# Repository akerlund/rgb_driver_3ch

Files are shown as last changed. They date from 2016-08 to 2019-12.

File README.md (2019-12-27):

# LED driver PCB, 3ch RGB

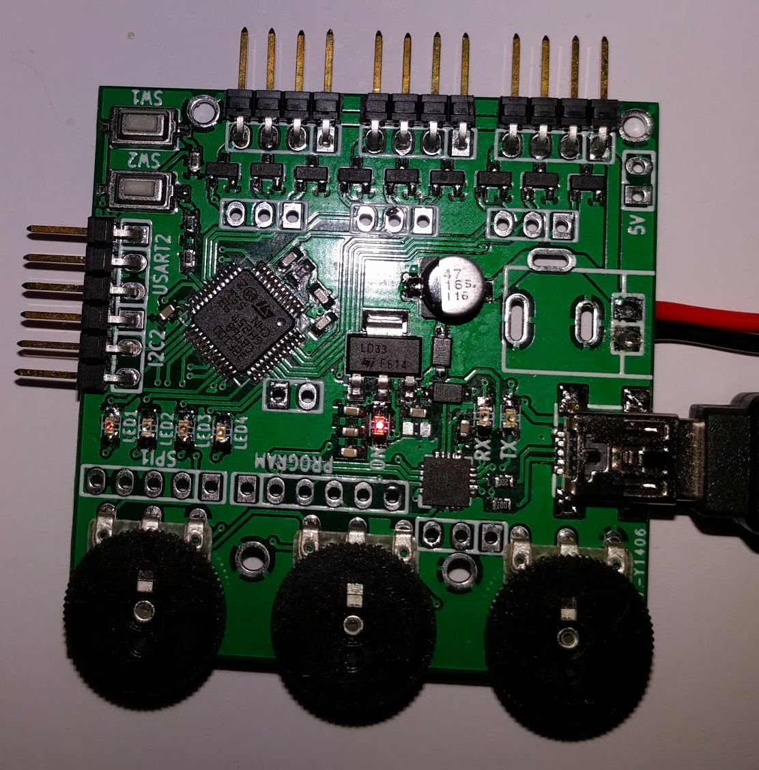
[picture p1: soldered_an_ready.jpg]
Version Three


STM32F100 microcontroller with small SOT23 MOSFETs to drive 12V LED strips.
Four LEDs and two buttons for custom use.
Three potentiometers for controlling the light; HSL, i.e., Hue, Saturation and Light.
A CP2102 serial to USB interface.
Pinout for other peripherals, i.e., I2C, SPI and UART.

## Build

Using the ARM compiler (arm-none-eabi), which can be installed with

```
sudo apt-get install gcc-arm-none-eabi
```
then change directory and run the make file
```
cd code
make
```

## Program
I use Devilholk's verion of [stm32flash](https://github.com/devilholk/stm32flash),
with a cheap CP2102 USB to UART Bridge Controller.

### Programming sequence example

```
~/rgb_driver_3ch$ stm32flash -b 115200 -Rcs.rts -Bcs.dtr -w code/build/driver_rgb_3ch.bin /dev/ttyUSB0
stm32flash - http://stm32flash.googlecode.com/

Using Parser : Raw BINARY
Serial Config: 115200 8E1
Version      : 0x22
Option 1     : 0x00
Option 2     : 0x00
Device ID    : 0x0420 (Medium-density VL)
RAM          : 8KiB  (512b reserved by bootloader)
Flash        : 128KiB (sector size: 4x1024)
Option RAM   : 15b
System RAM   : 2KiB

Wrote address 0x08003304 (100.00%) Done.
```

### Pin configurations
Make sure you connect cables like this;

PCB | CP2102
-- | --
3.3V | N/C
GND | GND
TX | RXI
RX | TXO
RESET | RTS
BOOT | DTR

If you haven't, remember to add your username to the dialout group

```
sudo adduser <user_name> dialout
```

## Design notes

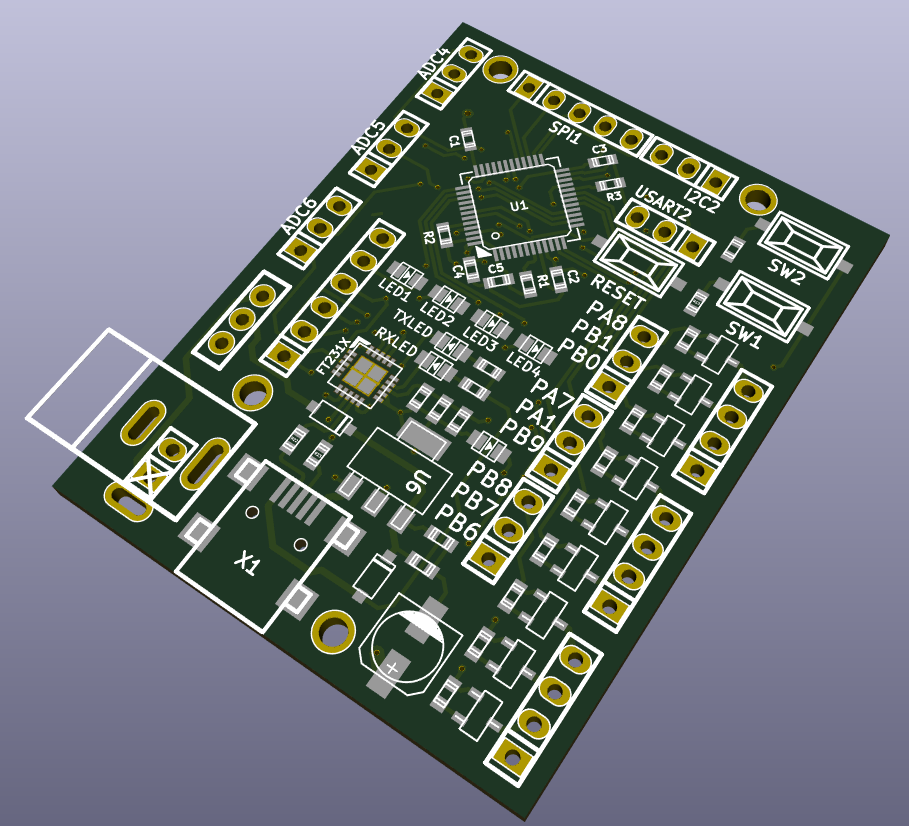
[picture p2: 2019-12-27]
kicad/version_2.png

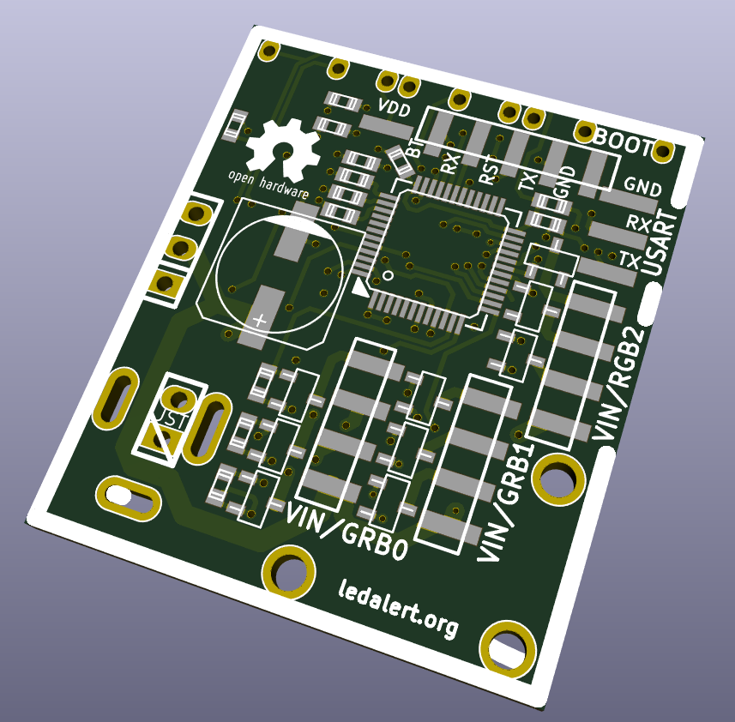
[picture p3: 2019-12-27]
kicad/version_1.png

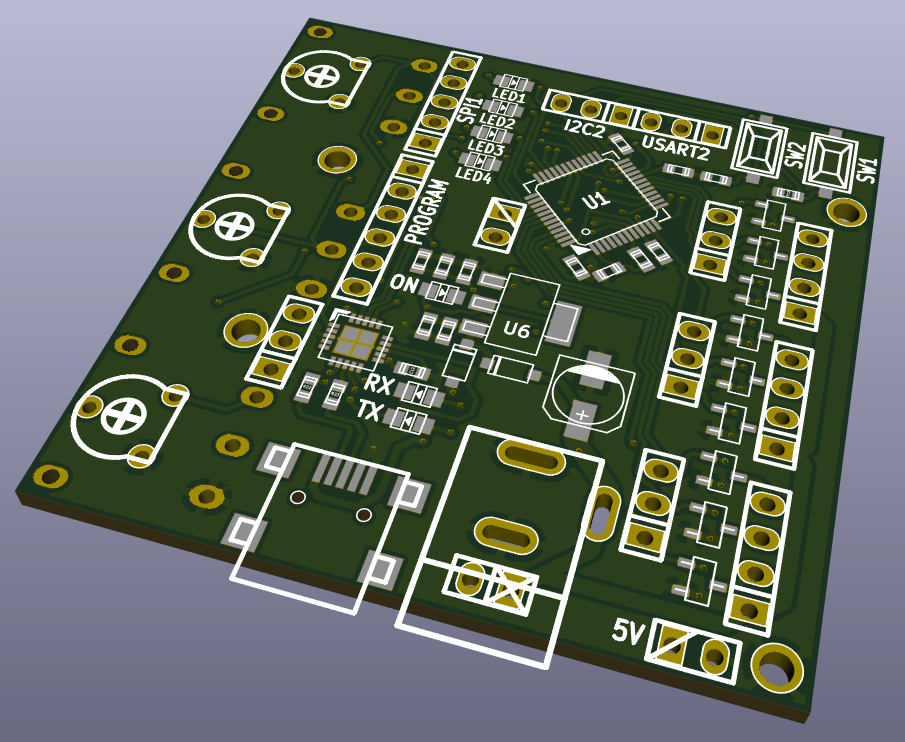
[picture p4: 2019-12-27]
kicad/version_3.png

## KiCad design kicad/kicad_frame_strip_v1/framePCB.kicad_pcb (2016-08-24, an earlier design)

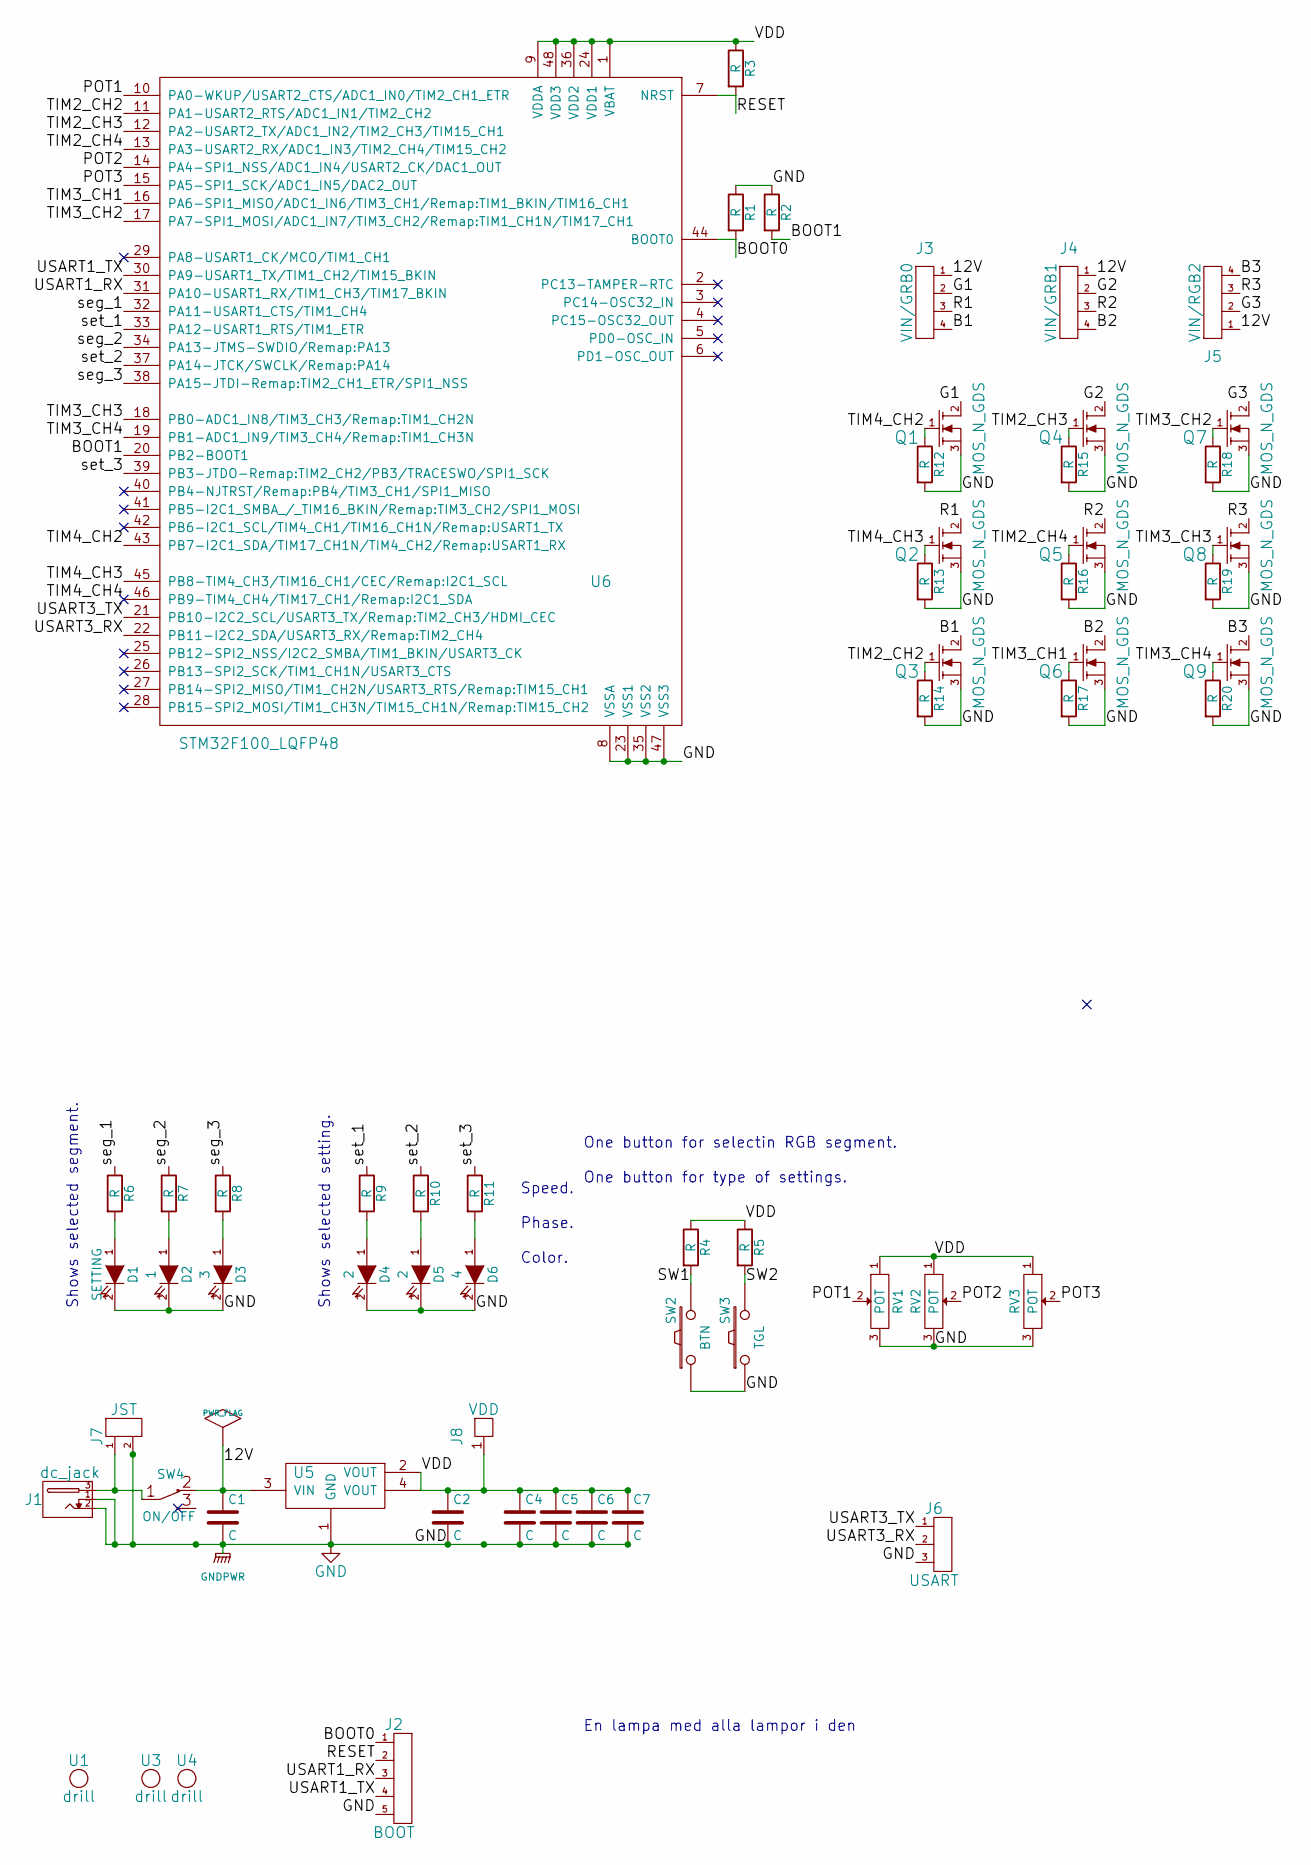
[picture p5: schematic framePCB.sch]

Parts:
C1: C; c_elec_8x6.5
C2, C4, C5, C6, C7: C; c_0603
D1: SETTING; Led_0603
D2: 1; Led_0603
D3: 3; Led_0603
D4, D5: 2; Led_0603
D6: 4; Led_0603
J1: dc_jack; dc_socket
J2: BOOT; smd_pin_5
J3: VIN/GRB0; smd_pin_4
J4: VIN/GRB1; smd_pin_4
J5: VIN/RGB2; smd_pin_4
J6: USART; smd_pin_3
J7: JST; pin_strip_2
J8: VDD; pin_strip_1
Q1, Q2, Q3, Q4, Q5, Q6, Q7, Q8, Q9: MOS_N_GDS; sot23
R1, R2, R3, R4, R5, R6, R7, R8, R9, R10, R11, R12, R13, R14, R15, R16, R17, R18, R19, R20: R; r_0603
RV1, RV2, RV3: POT; pot_eBay
SW2: BTN; smd_switch
SW3: TGL; smd_switch
SW4: ON/OFF; pin_socket_3
U1, U3, U4: drill; drill_2.0mm
U5: V_Reg_SOT; sot223
U6: STM32F100_LQFP48; lqfp48

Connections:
/12V: C1.1, J3.1, J4.1, J5.1, SW4.2 (NC), U5.3 (VIN)
/B1: J3.4, Q3.2 (D)
/B2: J4.4, Q6.2 (D)
/B3: J5.4, Q9.2 (D)
/BOOT0: J2.1, R1.2, U6.44 (BOOT0)
/BOOT1: R2.2, U6.20 (PB2-BOOT1)
/G1: J3.2, Q1.2 (D)
/G2: J4.2, Q4.2 (D)
/G3: J5.2, Q7.2 (D)
/POT1: RV1.2, U6.10 (PA0-WKUP/USART2_CTS/ADC1_IN0/TIM2_CH1_E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)
/POT2: RV2.2, U6.14 (PA4-SPI1_NSS/ADC1_IN4/USART2_CK/DAC1_OUT)
/POT3: RV3.2, U6.15 (PA5-SPI1_SCK/ADC1_IN5/DAC2_OUT)
/R1: J3.3, Q2.2 (D)
/R2: J4.3, Q5.2 (D)
/R3: J5.3, Q8.2 (D)
/RESET: J2.2, R3.2, U6.7 (NRST)
/SW1: R4.2, SW2.2
/SW2: R5.2, SW3.2
/TIM2_CH2: Q3.1 (G), R14.1, U6.11 (PA1-USART2_RTS/ADC1_IN1/TIM2_CH2)
/TIM2_CH3: Q4.1 (G), R15.1, U6.12 (PA2-USART2_TX/ADC1_IN2/TIM2_CH3/TIM15_C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)
/TIM2_CH4: Q5.1 (G), R16.1, U6.13 (PA3-USART2_RX/ADC1_IN3/TIM2_CH4/TIM15_C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)
/TIM3_CH1: Q6.1 (G), R17.1, U6.16 (PA6-SPI1_MISO/ADC1_IN6/TIM3_CH1/Remap:T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)
/TIM3_CH2: Q7.1 (G), R18.1, U6.17 (PA7-SPI1_MOSI/ADC1_IN7/TIM3_CH2/Remap:T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)
/TIM3_CH3: Q8.1 (G), R19.1, U6.18 (PB0-ADC1_IN8/TIM3_CH3/Remap:TIM1_CH2N)
/TIM3_CH4: Q9.1 (G), R20.1, U6.19 (PB1-ADC1_IN9/TIM3_CH4/Remap:TIM1_CH3N)
/TIM4_CH2: Q1.1 (G), R12.1, U6.43 (PB7-I2C1_SDA/TIM17_CH1N/TIM4_CH2/Remap: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)
/TIM4_CH3: Q2.1 (G), R13.1, U6.45 (PB8-TIM4_CH3/TIM16_CH1/CEC/Remap:I2C1_S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)
/USART1_RX: J2.3, U6.31 (PA10-USART1_RX/TIM1_CH3/TIM17_BKIN)
/USART1_TX: J2.4, U6.30 (PA9-USART1_TX/TIM1_CH2/TIM15_BKIN)
/USART3_RX: J6.2, U6.22 (PB11-I2C2_SDA/USART3_RX/Remap:TIM2_CH4)
/USART3_TX: J6.1, U6.21 (PB10-I2C2_SCL/USART3_TX/Remap:TIM2_CH3/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)
/VDD: C2.1, C4.1, C5.1, C6.1, C7.1, J8.1, R3.1, R4.1, R5.1, RV1.1, RV2.1, RV3.1, U5.2 (VOUT), U5.4 (VOUT), U6.1 (VBAT), U6.9 (VDDA), U6.24 (VDD1), U6.36 (VDD2), U6.48 (VDD3)
/seg_1: R6.1, U6.32 (PA11-USART1_CTS/TIM1_CH4)
/seg_2: R7.1, U6.34 (PA13-JTMS-SWDIO/Remap:PA13)
/seg_3: R8.1, U6.38 (PA15-JTDI-Remap:TIM2_CH1_ETR/SPI1_NSS)
/set_1: R9.1, U6.33 (PA12-USART1_RTS/TIM1_ETR)
/set_2: R10.1, U6.37 (PA14-JTCK/SWCLK/Remap:PA14)
/set_3: R11.1, U6.39 (PB3-JTDO-Remap:TIM2_CH2/PB3/TRACESWO/SP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)
GNDPWR: C1.2, C2.2, C4.2, C5.2, C6.2, C7.2, D1.2 (K), D2.2 (K), D3.2 (K), D4.2 (K), D5.2 (K), D6.2 (K), J1.1, J1.2, J2.5, J6.3, J7.2, Q1.3 (S), Q2.3 (S), Q3.3 (S), Q4.3 (S), Q5.3 (S), Q6.3 (S), Q7.3 (S), Q8.3 (S), Q9.3 (S), R1.1, R2.1, R12.2, R13.2, R14.2, R15.2, R16.2, R17.2, R18.2, R19.2, R20.2, RV1.3, RV2.3, RV3.3, SW2.1, SW3.1, U5.1 (GND), U6.8 (VSSA), U6.23 (VSS1), U6.35 (VSS2), U6.47 (VSS3)
unnamed: D1.1 (A), R6.2
unnamed: D2.1 (A), R7.2
unnamed: D3.1 (A), R8.2
unnamed: D4.1 (A), R9.2
unnamed: D5.1 (A), R10.2
unnamed: D6.1 (A), R11.2
unnamed: J1.3, J7.1, SW4.1 (COM)

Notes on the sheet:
One button for selectin RGB segment. One button for type of settings.
Shows selected segment.
Shows selected setting.
Speed. Phase. Color.
En lampa med alla lampor i den

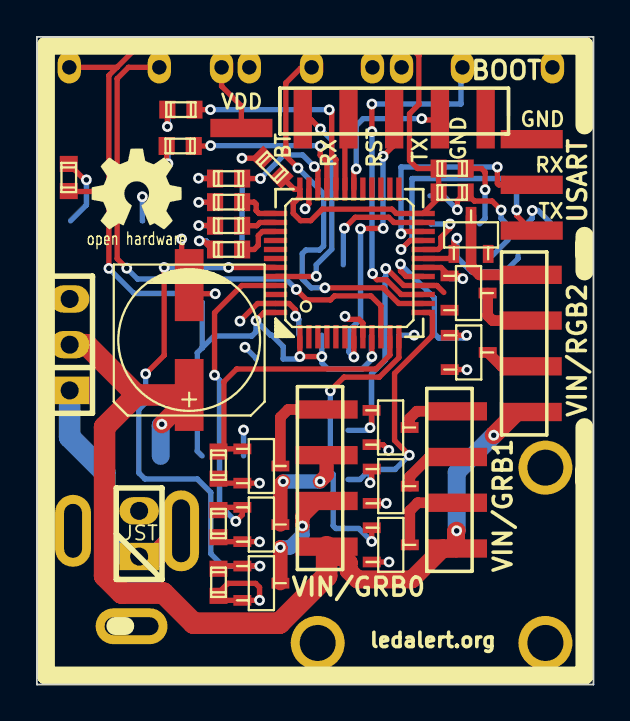
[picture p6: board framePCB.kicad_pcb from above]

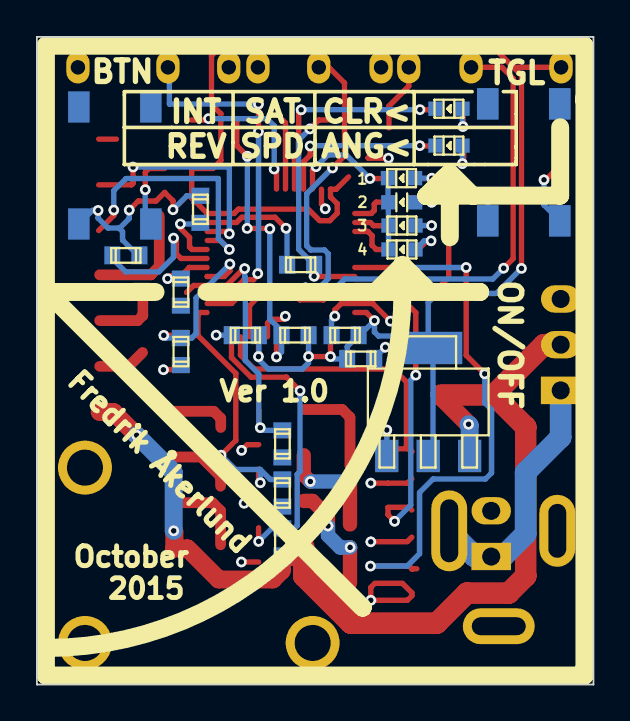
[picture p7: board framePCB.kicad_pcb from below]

Board: 2 copper layers, 30.9 x 36.0 mm, 60 parts (21 on the bottom side), 46 nets.

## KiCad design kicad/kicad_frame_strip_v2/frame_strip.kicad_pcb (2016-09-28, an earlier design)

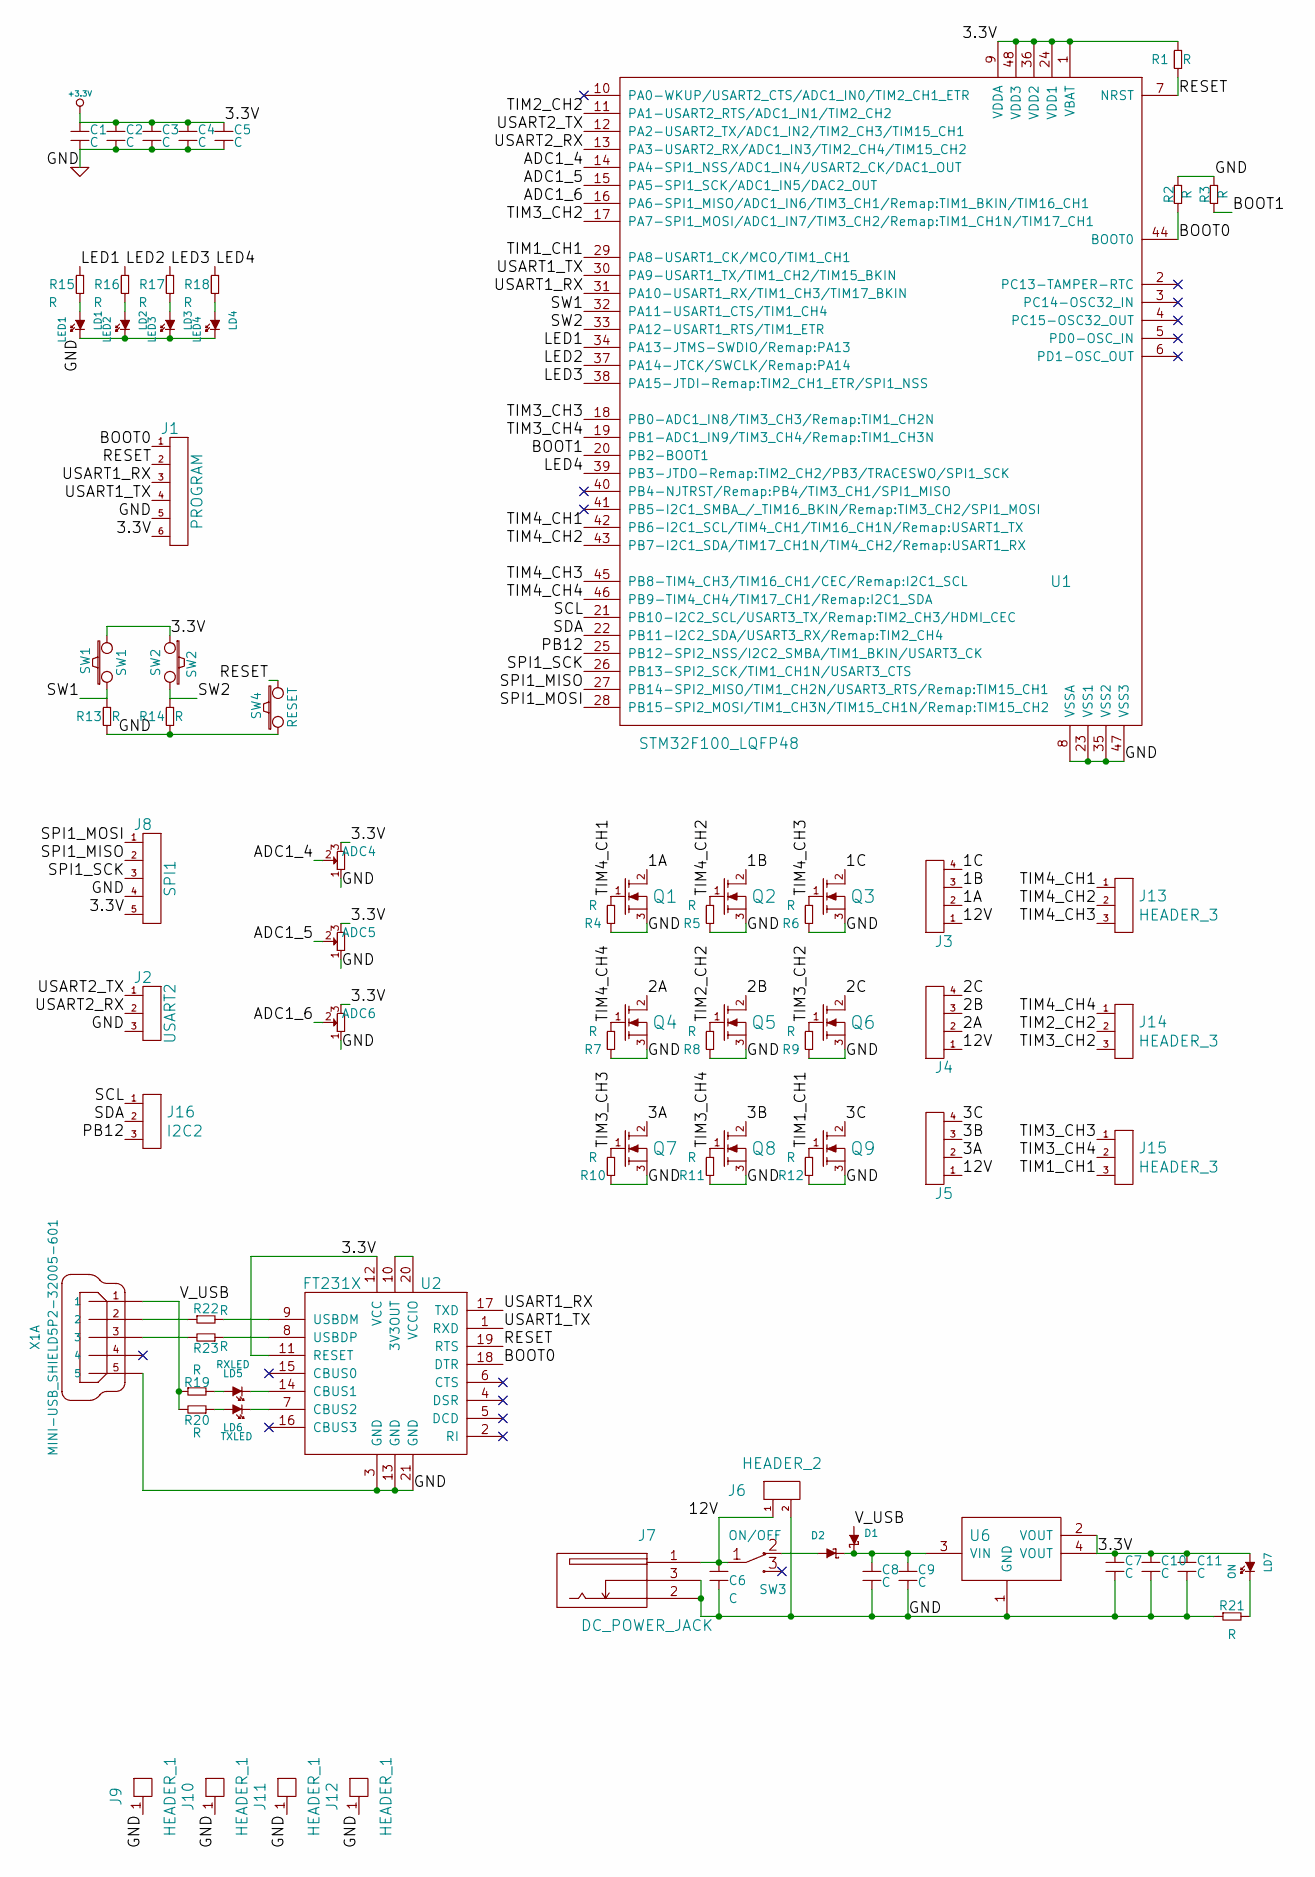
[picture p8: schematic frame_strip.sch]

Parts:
ADC4, ADC5, ADC6: POT; pin_socket_3
C1, C2, C3, C4, C5, C7, C8, C9, C10, C11: C; c_0603
C6: C; c_elec_5x5.3
D1, D2: SCHOTTKY; sod123
J1: PROGRAM; pin_strip_6
J2: USART2; pin_strip_3
J3, J4, J5: HEADER_4; pin_strip_4
J6: HEADER_2; pin_socket_2
J7: DC_POWER_JACK; dc_socket
J8: SPI1; pin_strip_5
J9, J10, J11, J12: HEADER_1; drill_2.0mm
J13, J14, J15: HEADER_3; pin_socket_3
J16: I2C2; pin_socket_3
LD1: LED1; Led_0805
LD2: LED2; Led_0805
LD3: LED3; Led_0805
LD4: LED4; Led_0805
LD5: RXLED; Led_0805
LD6: TXLED; Led_0805
LD7: ON; Led_0805
Q1, Q2, Q3, Q4, Q5, Q6, Q7, Q8, Q9: MOS_N_GDS; sot23
R1, R2, R3, R4, R5, R6, R7, R8, R9, R10, R11, R12, R13, R14, R15, R16, R17, R18, R19, R20, R21, R22, R23: R; r_0603
SW1: SW1; smd_push
SW2: SW2; smd_push
SW3: ON/OFF; switch_mmp122-r
SW4: RESET; smd_push
U1: STM32F100_LQFP48; lqfp48
U2: FT231X; qfn-20
U6: sot223
X1: MINI-USB_SHIELD5P2-32005-601; conn_usb_B_mini_smd

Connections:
+3.3V: ADC4.3, ADC5.3, ADC6.3, C1.1, C2.1, C3.1, C4.1, C5.1, C7.1, C10.1, C11.1, J1.6, J8.5, LD7.1 (A), R1.1, SW1.2, SW2.1, U1.1 (VBAT), U1.9 (VDDA), U1.24 (VDD1), U1.36 (VDD2), U1.48 (VDD3), U2.11 (RESET), U2.12 (VCC), U6.2 (VOUT), U6.4 (VOUT)
/1A: J3.2, Q1.2 (D)
/1B: J3.3, Q2.2 (D)
/1C: J3.4, Q3.2 (D)
/2A: J4.2, Q4.2 (D)
/2B: J4.3, Q5.2 (D)
/2C: J4.4, Q6.2 (D)
/3A: J5.2, Q7.2 (D)
/3B: J5.3, Q8.2 (D)
/3C: J5.4, Q9.2 (D)
/12V: C6.1, J3.1, J4.1, J5.1, J6.1, J7.1, SW3.1 (COM)
/ADC1_4: ADC4.2, U1.14 (PA4-SPI1_NSS/ADC1_IN4/USART2_CK/DAC1_OUT)
/ADC1_5: ADC5.2, U1.15 (PA5-SPI1_SCK/ADC1_IN5/DAC2_OUT)
/ADC1_6: ADC6.2, U1.16 (PA6-SPI1_MISO/ADC1_IN6/TIM3_CH1/Remap:T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)
/BOOT0: J1.1, R2.2, U1.44 (BOOT0), U2.18 (DTR)
/BOOT1: R3.2, U1.20 (PB2-BOOT1)
/LED1: R15.1, U1.34 (PA13-JTMS-SWDIO/Remap:PA13)
/LED2: R16.1, U1.37 (PA14-JTCK/SWCLK/Remap:PA14)
/LED3: R17.1, U1.38 (PA15-JTDI-Remap:TIM2_CH1_ETR/SPI1_NSS)
/LED4: R18.1, U1.39 (PB3-JTDO-Remap:TIM2_CH2/PB3/TRACESWO/SP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)
/PB12: J16.3, U1.25 (PB12-SPI2_NSS/I2C2_SMBA/TIM1_BKIN/USART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)
/RESET: J1.2, R1.2, SW4.2, U1.7 (NRST), U2.19 (RTS)
/SCL: J16.1, U1.21 (PB10-I2C2_SCL/USART3_TX/Remap:TIM2_CH3/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)
/SDA: J16.2, U1.22 (PB11-I2C2_SDA/USART3_RX/Remap:TIM2_CH4)
/SPI1_MISO: J8.2, U1.27 (PB14-SPI2_MISO/TIM1_CH2N/USART3_RTS/Rem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)
/SPI1_MOSI: J8.1, U1.28 (PB15-SPI2_MOSI/TIM1_CH3N/TIM15_CH1N/Rem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)
/SPI1_SCK: J8.3, U1.26 (PB13-SPI2_SCK/TIM1_CH1N/USART3_CTS)
/SW1: R13.1, SW1.1, U1.32 (PA11-USART1_CTS/TIM1_CH4)
/SW2: R14.1, SW2.2, U1.33 (PA12-USART1_RTS/TIM1_ETR)
/TIM1_CH1: J15.3, Q9.1 (G), R12.1, U1.29 (PA8-USART1_CK/MCO/TIM1_CH1)
/TIM2_CH2: J14.2, Q5.1 (G), R8.1, U1.11 (PA1-USART2_RTS/ADC1_IN1/TIM2_CH2)
/TIM3_CH2: J14.3, Q6.1 (G), R9.1, U1.17 (PA7-SPI1_MOSI/ADC1_IN7/TIM3_CH2/Remap:T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)
/TIM3_CH3: J15.1, Q7.1 (G), R10.1, U1.18 (PB0-ADC1_IN8/TIM3_CH3/Remap:TIM1_CH2N)
/TIM3_CH4: J15.2, Q8.1 (G), R11.1, U1.19 (PB1-ADC1_IN9/TIM3_CH4/Remap:TIM1_CH3N)
/TIM4_CH1: J13.1, Q1.1 (G), R4.1, U1.42 (PB6-I2C1_SCL/TIM4_CH1/TIM16_CH1N/Remap: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)
/TIM4_CH2: J13.2, Q2.1 (G), R5.1, U1.43 (PB7-I2C1_SDA/TIM17_CH1N/TIM4_CH2/Remap: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)
/TIM4_CH3: J13.3, Q3.1 (G), R6.1, U1.45 (PB8-TIM4_CH3/TIM16_CH1/CEC/Remap:I2C1_S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)
/TIM4_CH4: J14.1, Q4.1 (G), R7.1, U1.46 (PB9-TIM4_CH4/TIM17_CH1/Remap:I2C1_SDA)
/USART1_RX: J1.3, U1.31 (PA10-USART1_RX/TIM1_CH3/TIM17_BKIN), U2.17 (TXD)
/USART1_TX: J1.4, U1.30 (PA9-USART1_TX/TIM1_CH2/TIM15_BKIN), U2.1 (RXD)
/USART2_RX: J2.2, U1.13 (PA3-USART2_RX/ADC1_IN3/TIM2_CH4/TIM15_C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)
/USART2_TX: J2.1, U1.12 (PA2-USART2_TX/ADC1_IN2/TIM2_CH3/TIM15_C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)
/V_USB: D1.1 (A), R19.1, R20.2, X1.1
GND: ADC4.1, ADC5.1, ADC6.1, C1.2, C2.2, C3.2, C4.2, C5.2, C6.2, C7.2, C8.2, C9.2, C10.2, C11.2, J1.5, J2.3, J6.2, J7.2, J7.3, J8.4, J9.1, J10.1, J11.1, J12.1, LD1.2 (K), LD2.2 (K), LD3.2 (K), LD4.2 (K), Q1.3 (S), Q2.3 (S), Q3.3 (S), Q4.3 (S), Q5.3 (S), Q6.3 (S), Q7.3 (S), Q8.3 (S), Q9.3 (S), R2.1, R3.1, R4.2, R5.2, R6.2, R7.2, R8.2, R9.2, R10.2, R11.2, R12.2, R13.2, R14.2, R21.1, SW4.1, U1.8 (VSSA), U1.23 (VSS1), U1.35 (VSS2), U1.47 (VSS3), U2.3 (GND), U2.13 (GND), U2.21 (GND), U6.1 (GND), X1.5
unnamed: C8.1, C9.1, D1.2 (K), D2.2 (K), U6.3 (VIN)
unnamed: D2.1 (A), SW3.2 (NC)
unnamed: LD1.1 (A), R15.2
unnamed: LD2.1 (A), R16.2
unnamed: LD3.1 (A), R17.2
unnamed: LD4.1 (A), R18.2
unnamed: LD5.1 (A), R19.2
unnamed: LD5.2 (K), U2.14 (CBUS1)
unnamed: LD6.1 (A), R20.1
unnamed: LD6.2 (K), U2.7 (CBUS2)
unnamed: LD7.2 (K), R21.2
unnamed: R22.1, X1.2
unnamed: R22.2, U2.9 (USBDM)
unnamed: R23.1, U2.8 (USBDP)
unnamed: R23.2, X1.3
unnamed: U2.10 (3V3OUT), U2.20 (VCCIO)

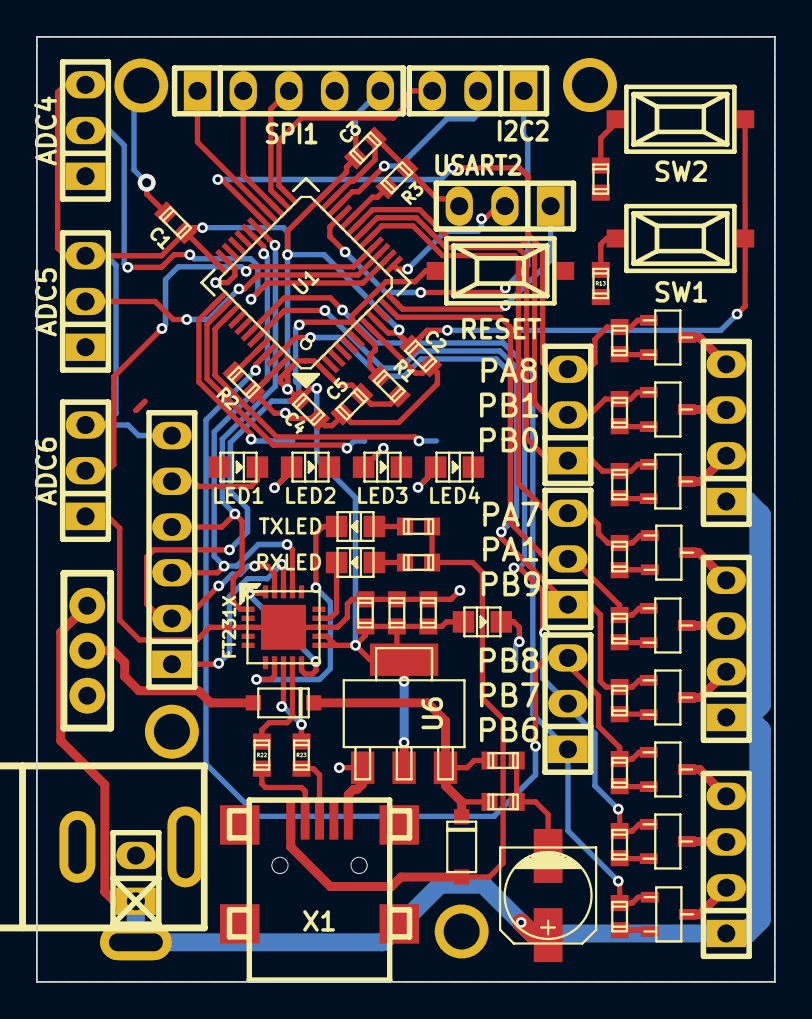
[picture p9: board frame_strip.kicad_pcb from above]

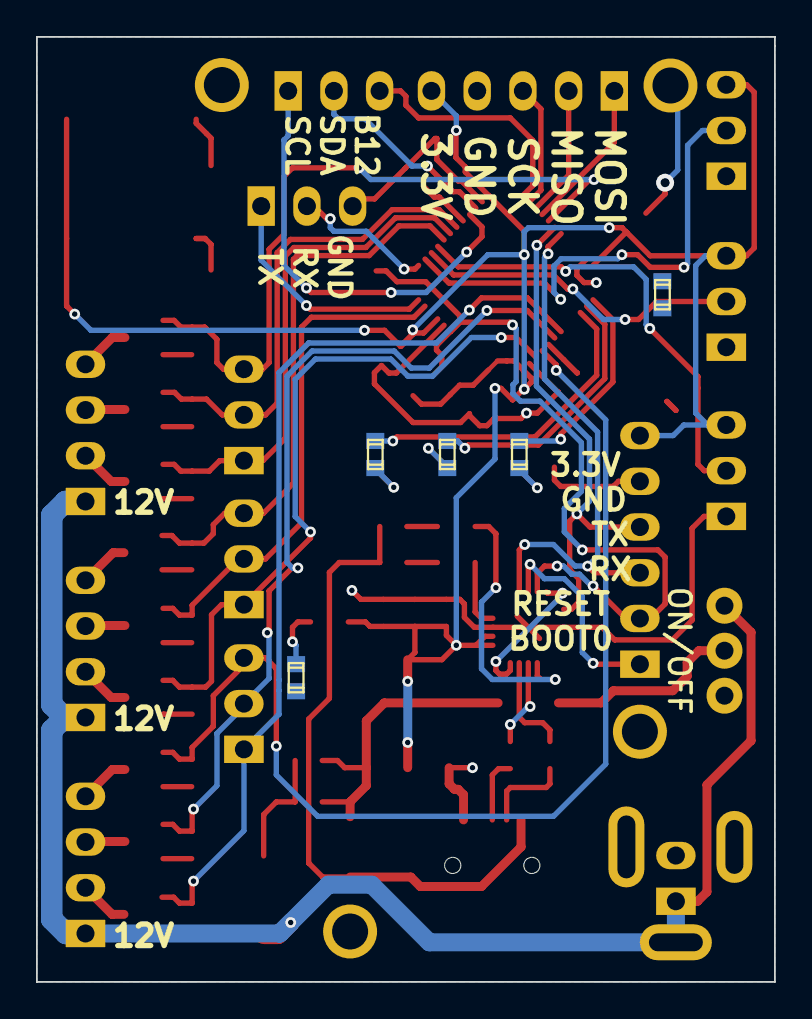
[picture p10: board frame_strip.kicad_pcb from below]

Board: 2 copper layers, 41.0 x 52.5 mm, 79 parts (5 on the bottom side), 60 nets.

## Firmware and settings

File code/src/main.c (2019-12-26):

#include <libopencm3/stm32/rcc.h>
#include <libopencm3/stm32/gpio.h>
#include <libopencm3/stm32/timer.h>
#include <libopencm3/stm32/dma.h>
#include <libopencm3/stm32/adc.h>
#include <libopencm3/stm32/usart.h>
#include <libopencm3/cm3/systick.h>
#include <libopencm3/cm3/nvic.h>

#include "gamma.h"
#include <stdio.h>

/*#define RMAX 4096
#define GMAX 4096
#define BMAX 4096*/

#define RMAX 4096
#define GMAX 3500
#define BMAX 2500

#define led_1 GPIO13
#define led_2 GPIO14
#define led_3 GPIO15
#define led_4 GPIO3

#define adc_pot1 GPIO4
#define adc_pot2 GPIO5
#define adc_pot3 GPIO6

#define btn_1 GPIO11
#define btn_2 GPIO12

// WS2812
#define NUMBER_LEDS 16
#define BIT_0 10
#define BIT_1 29
#define FREQ 400000

const uint16_t    gamma_lut[4096] = {GAMMA_LUT};
volatile uint16_t adc_samples[16];
volatile int      ms_time_delay;
volatile uint8_t  usart_rx_buffer[64];
volatile bool     usart_recieved = false;
volatile uint32_t idle_state_LED_blinker_cnt = 0;

// A struct for keeping track of an average ADC value.
struct value_handler {
  uint32_t  size;
  uint16_t* list;
  uint16_t  index;
};

// A struct for saving data of LED strips.
struct led_strip {
  int H;
  int S;
  int L;
};

// For deciding which LEDs to light up, and to what strip
// the inputs are directed to.
enum states {
  IDLE,
  AUTO,
  STRIP_1,
  STRIP_2,
  STRIP_3
};

// States for a button, for dealing with debouncing.
enum button_states {
  NOT_PUSHED,
  BOUNCE_KEEP,
  PUSHED,
  SUSTAINED
};

// WS2812
struct color {
  uint8_t r;
  uint8_t g;
  uint8_t b;
};

volatile uint8_t led_output_buf[NUMBER_LEDS*24+1];  //42 x 24
volatile struct  color led_input_buf[NUMBER_LEDS];


void sys_tick_handler(void){
  if (ms_time_delay) {
    ms_time_delay--;
  }
}


void sleep_ms(int t){
  ms_time_delay = t;
  while (ms_time_delay);
}


void setup_clock( ){

  rcc_clock_setup_in_hsi_out_24mhz( );

  rcc_periph_clock_enable(RCC_GPIOA);
  rcc_periph_clock_enable(RCC_GPIOB);
  rcc_periph_clock_enable(RCC_AFIO);

  //rcc_periph_clock_enable(RCC_USART2);
  rcc_periph_clock_enable(RCC_ADC1);

  rcc_periph_clock_enable(RCC_TIM1);
  rcc_periph_clock_enable(RCC_TIM2);
  rcc_periph_clock_enable(RCC_TIM3);
  rcc_periph_clock_enable(RCC_TIM4);

  rcc_periph_clock_enable(RCC_DMA1);
}


void setup_timers( ){

  void setup_timer1( ){

    // Clock division ratio and center aligned mode selection.
    TIM1_CR1 = TIM_CR1_CKD_CK_INT | TIM_CR1_CMS_EDGE;

    // Auto reload register.
    TIM1_ARR = 4096-1;

    // Prescaler.
    TIM1_PSC = 0;

    // Event generation register 0 update generation.
    TIM1_EGR = TIM_EGR_UG;

    TIM1_BDTR |= TIM_BDTR_MOE;

    // Output compare 3 mode and preload.
    // Capture/compare mode register, output compare 1 mode,
    // preload enable.
    TIM1_CCMR1 |= TIM_CCMR1_OC2M_PWM1 | TIM_CCMR1_OC2PE;
    TIM1_CCMR1 |= TIM_CCMR1_OC1M_PWM1 | TIM_CCMR1_OC1PE;
    TIM1_CCMR2 |= TIM_CCMR2_OC3M_PWM1 | TIM_CCMR2_OC3PE;
    TIM1_CCMR2 |= TIM_CCMR2_OC4M_PWM1 | TIM_CCMR2_OC4PE;

    // Polarity and state.
    TIM1_CCER |= TIM_CCER_CC1E;

    // ARR reload enable.
    TIM1_CR1 |= TIM_CR1_ARPE;

    // Counter enable.
    TIM1_CR1 |= TIM_CR1_CEN;
  }


  void setup_timer2( ){

    // Clock division ratio and center aligned mode selection.
    TIM2_CR1 = TIM_CR1_CKD_CK_INT | TIM_CR1_CMS_EDGE;

    // Auto reload register.
    TIM2_ARR = 4096-1;

    // Prescaler.
    TIM2_PSC = 0;

    // event generation register 0 update generation.
    TIM2_EGR = TIM_EGR_UG;

    // Output compare 3 mode and preload.
    // Capture/compare mode register, output compare 1 mode,
    // preload enable.
    TIM2_CCMR1 |= TIM_CCMR1_OC1M_PWM1 | TIM_CCMR1_OC1PE | TIM_CCMR1_OC2M_PWM1 | TIM_CCMR1_OC2PE;
    TIM2_CCMR2 |= TIM_CCMR2_OC3M_PWM1 | TIM_CCMR2_OC3PE | TIM_CCMR2_OC4M_PWM1 | TIM_CCMR2_OC4PE;

    // Polarity and state.
    TIM2_CCER |= TIM_CCER_CC2E | TIM_CCER_CC3E | TIM_CCER_CC4E;

    // ARR reload enable.
    TIM2_CR1 |= TIM_CR1_ARPE;

    // Counter enable.
    TIM2_CR1 |= TIM_CR1_CEN;
  }

  void setup_timer3( ){

    // Clock division ratio and center aligned mode selection.
    TIM3_CR1 = TIM_CR1_CKD_CK_INT | TIM_CR1_CMS_EDGE;

    // Period
    TIM3_ARR = 4096-1;

    // Prescaler
    TIM3_PSC = 0;
    TIM3_EGR = TIM_EGR_UG;

    // Output compare 3 mode and preload.
    TIM3_CCMR1 |= TIM_CCMR1_OC1M_PWM1 | TIM_CCMR1_OC1PE | TIM_CCMR1_OC2M_PWM1 | TIM_CCMR1_OC2PE;
    TIM3_CCMR2 |= TIM_CCMR2_OC3M_PWM1 | TIM_CCMR2_OC3PE | TIM_CCMR2_OC4M_PWM1 | TIM_CCMR2_OC4PE;

    // Polarity and state.
    TIM3_CCER |= TIM_CCER_CC1E | TIM_CCER_CC2E | TIM_CCER_CC3E | TIM_CCER_CC4E;

    // ARR reload enable.
    TIM3_CR1 |= TIM_CR1_ARPE;

    // Counter enable.
    TIM3_CR1 |= TIM_CR1_CEN;
  }

  void setup_timer4( ){

    // Clock division ratio and center aligned mode selection.
    TIM4_CR1 = TIM_CR1_CKD_CK_INT | TIM_CR1_CMS_EDGE;

    // Period.
    TIM4_ARR = 4096-1;

    // Prescaler.
    TIM4_PSC = 0;
    TIM4_EGR = TIM_EGR_UG;

    // Output compare 3 mode and preload.
    TIM4_CCMR2 |= TIM_CCMR2_OC3M_PWM1 | TIM_CCMR2_OC3PE | TIM_CCMR2_OC4M_PWM1 | TIM_CCMR2_OC4PE;
    TIM4_CCMR1 |= TIM_CCMR1_OC1M_PWM1 | TIM_CCMR1_OC1PE | TIM_CCMR1_OC2M_PWM1 | TIM_CCMR1_OC2PE;

    // Polarity and state.
    TIM4_CCER |= TIM_CCER_CC1E | TIM_CCER_CC2E | TIM_CCER_CC3E | TIM_CCER_CC4E;

    // ARR reload enable.
    TIM4_CR1 |= TIM_CR1_ARPE;

    // Counter enable.
    TIM4_CR1 |= TIM_CR1_CEN;
  }

  /*
    tim1_ch1 A8
    tim3_ch4 B1
    tim3_ch3 B0

    tim3_ch2 A7
    tim2_ch2 A1
    tim4_ch4 B9

    tim4_ch3 B8
    tim4_ch2 B7
    tim4_ch1 B6
  */

  gpio_set_mode(GPIOA, GPIO_MODE_OUTPUT_10_MHZ, GPIO_CNF_OUTPUT_ALTFN_PUSHPULL,
                GPIO1 | GPIO7 | GPIO8);
  gpio_set_mode(GPIOB, GPIO_MODE_OUTPUT_10_MHZ, GPIO_CNF_OUTPUT_ALTFN_PUSHPULL,
                GPIO0 | GPIO1 | GPIO6 | GPIO7 | GPIO8 | GPIO9);

  setup_timer1( );
  setup_timer2( );
  setup_timer3( );
  setup_timer4( );
}


void setup_timer_for_ws2812( ){

  // LED data out
  gpio_set(GPIOB, GPIO0);
  gpio_set_mode(GPIOB, GPIO_MODE_OUTPUT_50_MHZ, GPIO_CNF_OUTPUT_ALTFN_PUSHPULL, GPIO0);

  TIM3_CR1 = TIM_CR1_CKD_CK_INT | TIM_CR1_CMS_EDGE;

  // Period
  TIM3_ARR = (24000000 / FREQ)-1;

  // Prescaler
  TIM3_PSC = 0;
  TIM3_EGR = TIM_EGR_UG;

  // Output compare 3 mode and preload
  TIM3_CCMR2 |= TIM_CCMR2_OC3M_PWM2 | TIM_CCMR2_OC3PE;

  // Polarity and state
  TIM3_CCER |= TIM_CCER_CC3E;

  // ARR reload enable
  TIM3_CR1 |= TIM_CR1_ARPE;

  // Counter enable
  TIM3_CR1 |= TIM_CR1_CEN;

  TIM3_CCR3 = 0;
}


void set_pwm_strip_1(int R, int G, int B) {

  int cR = gamma_lut[ (R*RMAX) >> 12 ];
  int cG = gamma_lut[ (G*GMAX) >> 12 ];
  int cB = gamma_lut[ (B*BMAX) >> 12 ];

  TIM1_CCR1 = cR;
  TIM3_CCR4 = cG;
  TIM3_CCR3 = cB;
}


void set_pwm_strip_2(int R, int G, int B) {

  int cR = gamma_lut[ (R*RMAX) >> 12 ];
  int cG = gamma_lut[ (G*GMAX) >> 12 ];
  int cB = gamma_lut[ (B*BMAX) >> 12 ];

  TIM3_CCR2 = cR;
  TIM2_CCR2 = cG;
  TIM4_CCR4 = cB;
}


void set_pwm_strip_3(int R, int G, int B) {

  int cR = gamma_lut[ (R*RMAX) >> 12 ];
  int cG = gamma_lut[ (G*GMAX) >> 12 ];
  int cB = gamma_lut[ (B*BMAX) >> 12 ];

  TIM4_CCR3 = cR;
  TIM4_CCR2 = cG;
  TIM4_CCR1 = cB;
}


void setup_usart_1( ) {

  gpio_set_mode(GPIOA, GPIO_MODE_INPUT, GPIO_CNF_INPUT_FLOAT, GPIO_USART1_RX);

  usart_set_baudrate(USART1, 921600);
  usart_set_databits(USART1, 8);
  usart_set_stopbits(USART1, USART_STOPBITS_1);
  usart_set_mode(USART1, USART_MODE_RX);
  usart_set_parity(USART1, USART_PARITY_NONE);
  usart_set_flow_control(USART1, USART_FLOWCONTROL_NONE);

  usart_enable(USART1);
}


void setup_usart_2(void){

  // Enable the USART1 interrupt.
  nvic_enable_irq(NVIC_USART2_IRQ);

  // GPIO port A.
  gpio_set_mode(GPIOA, GPIO_MODE_OUTPUT_50_MHZ,
          GPIO_CNF_OUTPUT_ALTFN_PUSHPULL, GPIO_USART2_TX);
  gpio_set_mode(GPIOA, GPIO_MODE_INPUT,
          GPIO_CNF_INPUT_FLOAT, GPIO_USART2_RX);

  // UART parameters.
  usart_set_baudrate(USART2, 115200);
  usart_set_databits(USART2, 8);
  usart_set_stopbits(USART2, USART_STOPBITS_1);
  usart_set_mode(USART2, USART_MODE_TX_RX);
  usart_set_parity(USART2, USART_PARITY_NONE);
  usart_set_flow_control(USART2, USART_FLOWCONTROL_NONE);

  // Enable USART1 Receive interrupt.
  usart_enable_rx_interrupt(USART2);
  usart_enable_tx_interrupt(USART2);


  // Enable the USART.
  usart_enable(USART2);
}


void usart2_isr(void){

  /* Check if we were called because of RXNE. */
  if (((USART_CR1(USART2) & USART_CR1_RXNEIE) != 0) &&
      ((USART_SR(USART2) & USART_SR_RXNE) != 0)) {


    /* Retrieve the data from the peripheral. */
    usart_rx_buffer[0] = usart_recv(USART2);
    usart_recieved = true;

    /* Enable transmit interrupt so it sends back the data. */

  }

  /* Check if we were called because of TXE. */
  if (((USART_CR1(USART2) & USART_CR1_TXEIE) != 0) &&
      ((USART_SR(USART2) & USART_SR_TXE) != 0)) {

    /* Put data into the transmit register. */
    //usart_send(USART2, &usart_rx_buffer);
    /* Disable the TXE interrupt, it's no longer needed. */
    USART_CR1(USART2) &= ~USART_CR1_TXEIE;

  }

}



void setup_LEDs( ){

  // For using PA13-15 and PB3.
  gpio_primary_remap(AFIO_MAPR_SWJ_CFG_JTAG_OFF_SW_OFF,0);

  // JTAG GPIOs remapped.
  gpio_set_mode(GPIOA, GPIO_MODE_OUTPUT_10_MHZ,
          GPIO_CNF_OUTPUT_PUSHPULL, led_1);
  gpio_set_mode(GPIOA, GPIO_MODE_OUTPUT_10_MHZ,
          GPIO_CNF_OUTPUT_PUSHPULL, led_2);
  gpio_set_mode(GPIOA, GPIO_MODE_OUTPUT_10_MHZ,
          GPIO_CNF_OUTPUT_PUSHPULL, led_3);
  gpio_set_mode(GPIOB, GPIO_MODE_OUTPUT_10_MHZ,
          GPIO_CNF_OUTPUT_PUSHPULL, led_4);

  gpio_clear(GPIOA, led_1);
  gpio_clear(GPIOA, led_2);
  gpio_clear(GPIOA, led_3);
  gpio_clear(GPIOB, led_4);
}



void setup_buttons( ){

  gpio_set_mode(GPIOA, GPIO_MODE_INPUT,
                GPIO_CNF_INPUT_FLOAT, GPIO11);

  gpio_set_mode(GPIOA, GPIO_MODE_INPUT,
                GPIO_CNF_INPUT_FLOAT, GPIO12);
}



inline void colorHexagon(int hue, int *R, int *G, int *B){

  int frac = hue >> 12;
  int ci = hue & 0xFFF;
  int cd = 4095 - ci;
  int cs = 4095;

  switch (frac) {
    case 0: *R = cs;  *G = ci;  *B = 0;  break;  // R1  G+  B0
    case 1: *R = cd;  *G = cs;  *B = 0;  break;  // R-  G1  B0
    case 2: *R = 0;   *G = cs;  *B = ci; break;  // R0  G1  B+
    case 3: *R = 0;   *G = cd;  *B = cs; break;  // R0  G-  B1
    case 4: *R = ci;  *G = 0;   *B = cs; break;  // R+  G0  B1
    case 5: *R = cs;  *G = 0;   *B = cd; break;  // R1  G0  B-
  }
}


colorHSL(int hue, int sat, int light,int *R, int *G, int *B) {

  int tR,tG,tB;
  int frac = hue >> 12;

  // Chroma.
  int C = ((4095-abs((light<<1)-4095))*sat)>>12;
  int X= (C*(4095-abs((hue % 8192) - 4095)))>>12;

  // Hue.
  switch (frac) {
    case 0:  tR = C;  tG = X;  tB = 0; break;  //R1  G+  B0
    case 1:  tR = X;  tG = C;  tB = 0; break;  //R-  G1  B0
    case 2:  tR = 0;  tG = C;  tB = X; break;  //R0  G1  B+
    case 3:  tR = 0;  tG = X;  tB = C; break;  //R0  G-  B1
    case 4:  tR = X;  tG = 0;  tB = C; break;  //R+  G0  B1
    case 5:  tR = C;  tG = 0;  tB = X; break;  //R1  G0  B-
  }

  // Lightness.
  int m = light - (C>>1);
  tR += m;
  tG += m;
  tB += m;

  *R = tR;
  *G = tG;
  *B = tB;
}


inline void colorHCY(int hue, int chroma, int luma,int *R, int *G, int *B) {

  int tR,tG,tB;
  int frac = hue >> 12;

  // Chroma.
  int C = chroma;
  int X = (C*(4095-abs((hue % 8192) - 4095))) >> 12;

  // Hue.
  switch (frac) {
    case 0:  tR = C;  tG = X;  tB = 0; break; // R1  G+  B0
    case 1:  tR = X;  tG = C;  tB = 0; break; // R-  G1  B0
    case 2:  tR = 0;  tG = C;  tB = X; break; // R0  G1  B+
    case 3:  tR = 0;  tG = X;  tB = C; break; // R0  G-  B1
    case 4:  tR = X;  tG = 0;  tB = C; break; // R+  G0  B1
    case 5:  tR = C;  tG = 0;  tB = X; break; // R1  G0  B-
  }

  // Luma.
  int m = luma - ((tR*1229 + tG*2417 + tB*451) >> 12);
  tR += m;
  tG += m;
  tB += m;

  #define Crowbar(x, min, max)  if (x>max) x=max; if (x<min) x=min

  Crowbar(tR, 0, 4095);
  Crowbar(tG, 0, 4095);
  Crowbar(tB, 0, 4095);

  *R = tR; *G = tG; *B = tB;
}


void USART_putn(uint32_t USARTx, volatile char *s, int size){

  if (!size) {
    return;
  }

  while(size--){
    usart_send_blocking(USARTx, *s);
    *s++;
  }
}


void USART_puts(uint32_t USARTx, volatile char *s){

  while(*s){
    usart_send_blocking(USARTx, *s);
    *s++;
  }
}


void setup_ADC( ){

  adc_off(ADC1);
  gpio_set_mode(GPIOA, GPIO_MODE_INPUT, GPIO_CNF_INPUT_ANALOG, GPIO4 | GPIO5 | GPIO6);

  adc_enable_scan_mode(ADC1);
  adc_set_single_conversion_mode(ADC1);

  adc_set_right_aligned(ADC1);
  adc_set_sample_time_on_all_channels(ADC1, ADC_SMPR_SMP_239DOT5CYC);
  adc_enable_external_trigger_regular(ADC1, ADC_CR2_EXTSEL_SWSTART);

  adc_power_on(ADC1);

  sleep_ms(2);

  adc_reset_calibration(ADC1);
  adc_calibration(ADC1);

  uint8_t channel_array[3];
  channel_array[0] = ADC_CHANNEL4;
  channel_array[1] = ADC_CHANNEL5;
  channel_array[2] = ADC_CHANNEL6;

  adc_set_regular_sequence(ADC1, 3, channel_array);


  dma_channel_reset(DMA1, DMA_CHANNEL1);
  dma_set_peripheral_address(DMA1, DMA_CHANNEL1, (uint32_t)&ADC1_DR);
  dma_set_memory_address(DMA1, DMA_CHANNEL1,(uint32_t)adc_samples);
  dma_set_number_of_data(DMA1, DMA_CHANNEL1, 3);
  dma_set_read_from_peripheral(DMA1, DMA_CHANNEL1);
  dma_enable_memory_increment_mode(DMA1, DMA_CHANNEL1);
  dma_enable_circular_mode(DMA1, DMA_CHANNEL1);
  dma_set_peripheral_size(DMA1, DMA_CHANNEL1, DMA_CCR_PSIZE_16BIT);
  dma_set_memory_size(DMA1, DMA_CHANNEL1, DMA_CCR_MSIZE_16BIT);
  dma_set_priority(DMA1, DMA_CHANNEL1, DMA_CCR_PL_VERY_HIGH);

  dma_enable_channel(DMA1, DMA_CHANNEL1);

  dma_enable_transfer_complete_interrupt(DMA1, DMA_CHANNEL1);

  nvic_set_priority(NVIC_DMA1_CHANNEL1_IRQ, 0);
  nvic_enable_irq(NVIC_DMA1_CHANNEL1_IRQ);

  adc_start_conversion_regular(ADC1);
  adc_enable_dma(ADC1);
}


void dma1_channel1_isr(void) {

  DMA1_IFCR |= DMA_IFCR_CTCIF1;
  adc_start_conversion_regular(ADC1);
}


uint16_t average_of_value_handler(struct value_handler *vh){

  uint16_t aver = 0;
  for(uint32_t i = 0; i < vh->size; i++){
    aver += vh->list[i];
  }
  aver = aver / vh->size;
  return aver;
}


void add_to_value_handler(struct value_handler *vh, uint16_t value){

  vh->list[vh->index] = value;
  vh->index += 1;
  if (vh->index == vh->size){
    vh->index = 0;
  }
}
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
int main( ){

  setup_clock( );

  systick_set_clocksource(STK_CSR_CLKSOURCE_AHB);
  systick_set_reload(12000-1);  // 1 kHz
  systick_interrupt_enable( );
  systick_counter_enable( );


  setup_LEDs( );
  setup_buttons( );

  setup_timers( );
  //setup_usart_2( );
  setup_ADC( );
  setup_usart_1( );


/*
//WS2812

  setup_LEDs( );
  setup_timer_for_ws2812( );


  populate_test_buffer();
  process_buffer();
  send_led_buffer_blocking( );

  while(1) {
    //recieve_led_data_blocking();
    sleep_ms(10);
    program_counter++;
    if(program_counter % 40 == 0){
      idle_state_LED_blinker( );
    }
    process_buffer( );
    send_led_buffer_blocking( );
  }
*/
  uint32_t program_counter = 0;

  // ADC average.
  struct value_handler adc_values1;
  adc_values1.size = 16;
  uint16_t adc1_list[adc_values1.size];
  adc_values1.list = &adc1_list;
  adc_values1.index = 0;
  uint16_t average = 0;

  // Declaring variables for the auto roll mode.
  //uint32_t program_counter = 0;
  uint32_t auto_roll_speed = 40;
  uint32_t auto_roll_is_paused = 0;
  uint32_t auto_roll_hue_strip_1 = 1333;
  uint32_t auto_roll_hue_strip_2 = 2666;
  uint32_t auto_roll_hue_strip_3 = 3999;

  // Declaring the state variables.
  enum states current_state = AUTO;
  enum button_states button_1_state = NOT_PUSHED;
  enum button_states button_2_state = NOT_PUSHED;


  // Declaring the LED strip structs.
  struct led_strip led_strip_1 = {1333,4095,2000};
  struct led_strip led_strip_2 = {2666,4095,2000};
  struct led_strip led_strip_3 = {3999,4095,2000};

  // Variables for PWM data, derived from hue variable.
  int R, G, B = 0;



  // Startup blinking function, for added coolness.
  //intro_blink( );

  while (1) {
    sleep_ms(1);
    program_counter++;

    // UART data.
    if (usart_recieved == true){
      usart_recieved = false;
    }

/*      add_to_value_handler(&adc_values1, adc_samples[2]);
      average = average_of_value_handler(&adc_values1);
*/

    // Checking the buttons and changing state.
    if (program_counter % 40 == 0) {
      // Checking button 1.
      if (gpio_get(GPIOA, btn_1) != 0) {
        if (button_1_state == NOT_PUSHED){
          button_1_state = PUSHED;
        } else {
          if (button_1_state == PUSHED){
            button_1_state = SUSTAINED;
          }
        }
      } else {
        button_1_state = NOT_PUSHED;
      }

      // Checking button 2.
      if (gpio_get(GPIOA, btn_2) != 0) {
        if (button_2_state == NOT_PUSHED){
          button_2_state = PUSHED;
        } else {
          if (button_2_state == PUSHED){
            button_2_state = SUSTAINED;
          }
        }
      } else {
        button_2_state = NOT_PUSHED;
      }

      // Changing state.
      if (button_1_state == PUSHED){
        if (current_state == STRIP_3){
          current_state = IDLE;
        } else {
          current_state++;
        }
      }

      // Pausing autoroll.
      if (button_2_state == PUSHED){
        if (current_state == AUTO){
          if (auto_roll_is_paused == 0){
            auto_roll_is_paused = 1;
          } else {
            auto_roll_is_paused = 0;
          }
        }
      }
    }

    // State depending actions, i.e., setting the PWMs, and saving the
    // inputs. If in a state of any strip, it will display the current
    // inputs of the ADC, otherwise it will use its saved data.
    // The four LEDs will indicate which state is the current.
    switch (current_state){
      case IDLE:

        if (program_counter % 500 == 0){
          idle_state_LED_blinker( );
        }

        colorHSL(led_strip_1.H*6, led_strip_1.S, led_strip_1.L, &R, &G, &B);
        set_pwm_strip_1(R, G, B);
        colorHSL(led_strip_2.H*6, led_strip_2.S, led_strip_2.L, &R, &G, &B);
        set_pwm_strip_2(R, G, B);
        colorHSL(led_strip_3.H*6, led_strip_3.S, led_strip_3.L, &R, &G, &B);
        set_pwm_strip_3(R, G, B);

        break;

      case AUTO:

        gpio_set(GPIOA,led_1);
        gpio_clear(GPIOA,led_2);
        gpio_clear(GPIOA,led_3);
        gpio_clear(GPIOB,led_4);

        if (auto_roll_is_paused == 0){
          auto_roll_speed = adc_samples[2]/400+1;
          if(program_counter % auto_roll_speed == 0){

            auto_roll_hue_strip_1++;
            auto_roll_hue_strip_2++;
            auto_roll_hue_strip_3++;
          }
        }
        colorHSL((auto_roll_hue_strip_1%4095)*6, 4095, adc_samples[0], &R, &G, &B);
        set_pwm_strip_1(R, G, B);
        colorHSL((auto_roll_hue_strip_2%4095)*6, 4095, adc_samples[0], &R, &G, &B);
        set_pwm_strip_2(R, G, B);
        colorHSL((auto_roll_hue_strip_3%4095)*6, 4095, adc_samples[0], &R, &G, &B);
        set_pwm_strip_3(R, G, B);

        break;

      case STRIP_1:

        gpio_clear(GPIOA,led_1);
        gpio_set(GPIOA,led_2);

        if (button_2_state == PUSHED){
          auto_roll_hue_strip_1 = adc_samples[2];
          led_strip_1.H = adc_samples[2];
          led_strip_1.S = adc_samples[1];
          led_strip_1.L = adc_samples[0];
        }
        colorHSL(adc_samples[2]*6, adc_samples[1], adc_samples[0], &R, &G, &B);
        set_pwm_strip_1(R, G, B);
        colorHSL(led_strip_2.H*6, led_strip_2.S, led_strip_2.L, &R, &G, &B);
        set_pwm_strip_2(R, G, B);
        colorHSL(led_strip_3.H*6, led_strip_3.S, led_strip_3.L, &R, &G, &B);
        set_pwm_strip_3(R, G, B);

        break;

      case STRIP_2:

        gpio_clear(GPIOA,led_2);
        gpio_set(GPIOA,led_3);

        if (button_2_state == PUSHED){
          auto_roll_hue_strip_2 = adc_samples[2];
          led_strip_2.H = adc_samples[2];
          led_strip_2.S = adc_samples[1];
          led_strip_2.L = adc_samples[0];
        }

        colorHSL(led_strip_1.H*6, led_strip_1.S, led_strip_1.L, &R, &G, &B);
        set_pwm_strip_1(R, G, B);
        colorHSL(adc_samples[2]*6, adc_samples[1], adc_samples[0], &R, &G, &B);
        set_pwm_strip_2(R, G, B);
        colorHSL(led_strip_3.H*6, led_strip_3.S, led_strip_3.L, &R, &G, &B);
        set_pwm_strip_3(R, G, B);

        break;

      case STRIP_3:

        gpio_clear(GPIOA,led_3);
        gpio_set(GPIOB,led_4);

        if (button_2_state == PUSHED){
          auto_roll_hue_strip_3 = adc_samples[2];
          led_strip_3.H = adc_samples[2];
          led_strip_3.S = adc_samples[1];
          led_strip_3.L = adc_samples[0];
        }

        colorHSL(led_strip_1.H*6, led_strip_1.S, led_strip_1.L, &R, &G, &B);
        set_pwm_strip_1(R, G, B);
        colorHSL(led_strip_2.H*6, led_strip_2.S, led_strip_2.L, &R, &G, &B);
        set_pwm_strip_2(R, G, B);
        colorHSL(adc_samples[2]*6, adc_samples[1], adc_samples[0], &R, &G, &B);
        set_pwm_strip_3(R, G, B);

        break;
    }
  }
  return 0;
}

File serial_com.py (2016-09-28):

import serial
import struct
import sys

def serial_func(mode):


	try:

		ser_com = serial.Serial('/dev/ttyUSB1', baudrate = 115200)

	except Exception as err:

		print ('Serial Exception')
		print (err)

	else:

		ser_com.flush( )

		#mode = 'tx0'

		if mode == 'rx0':
			try:

				while True:

					print ('Reading bytes.')
					read_data = ser_com.read(1)
					byte_rec = (struct.unpack('c',read_data)[0])
					print (byte_rec)
					print (type(byte_rec))

			except KeyboardInterrupt:

				print ('KeyboardInterrupt. Exiting.')


		elif mode == 'rx1':

			recieved = 0
			try:

				while True:

					read_data = ser_com.read(2)
					byte_rec = (struct.unpack('H',read_data)[0])
					print ('%i: %i.' % (recieved, byte_rec))
					
					recieved += 1
					if recieved == 16:
						recieved = 0

			except KeyboardInterrupt:

				print ('KeyboardInterrupt. Exiting.')


		elif mode == 'rx2':
			try:

				while True:

					print ('Reading ADC.')
					read_data = ser_com.read(2)
					byte_rec = (struct.unpack('H',read_data))
					for bytess in byte_rec:
						print(bytess)

			except KeyboardInterrupt:

				print ('KeyboardInterrupt. Exiting.')




		elif mode == 'tx0':
			try:

				while True:

					input_line = input ('Send data. > ')
					print (input_line)
					if input_line.isdigit( ):
						ser_com.write(struct.pack('h',int(input_line)))
						ser_com.flush()
						print ('Sent data: %s.' % input_line)

			except KeyboardInterrupt:

				print ('KeyboardInterrupt. Exiting.')



		ser_com.close( )

if __name__ == '__main__':

	print(sys.argv[1])
	serial_func(sys.argv[1])

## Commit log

2016-08-09 The new PCB
    [frame_strip.kicad_pcb, frame_strip.sch]
2016-08-24 PCB, code
    [framePCB.kicad_pcb, frame_strip.kicad_pcb, frame_strip.sch]
2016-09-28 Version 3 PCB
    [framePCB.sch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]
2019-12-26 Created a KiCad folder
    [framePCB-B_Cu.gbl, framePCB-B_Mask.gbs, framePCB-B_SilkS.gbo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]
2019-12-26 PCB pictures
